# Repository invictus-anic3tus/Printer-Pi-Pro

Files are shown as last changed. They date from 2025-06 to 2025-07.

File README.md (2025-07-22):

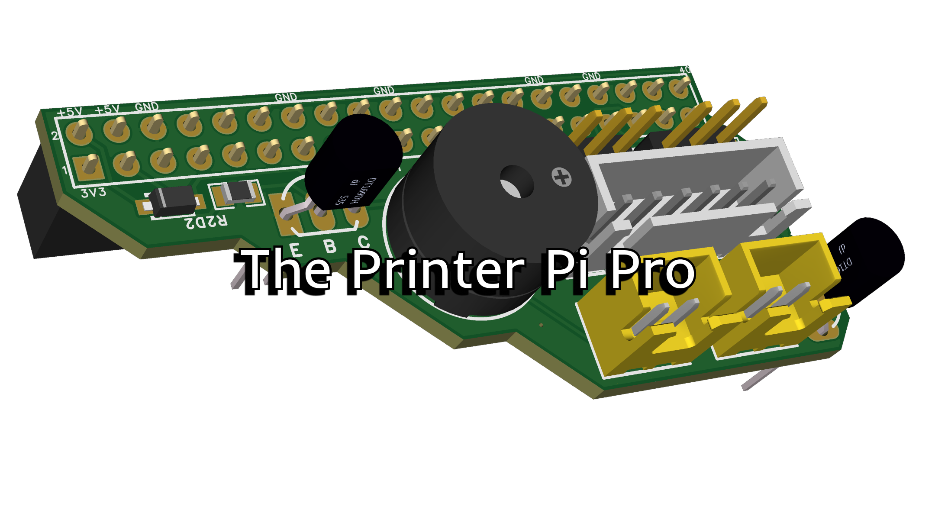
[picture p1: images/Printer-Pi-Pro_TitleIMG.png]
Title Image
# 

<h3 align="center">The all-in-one Raspberry Pi hat for controlling your 3D printer!</h3>

<p align="center">
  
  
</p>

The Printer Pi Pro is a Raspberry Pi HAT for a Klipper or Octoprint 3D printer host. The HAT controls things like servos, an accelerometer, a fan for cooling the pi, and more. It also controls a relay that can turn your printer on or off!

## Contents!! Yay!!
- [Features](#features)
- [Setup](#setup)
  - [Buzzer](#music-with-the-buzzer)
  - [Fan](#controlling-the-fan)
  - [Servos](#controlling-servos)
  - [Input Shaping](#input-shaping-with-the-adxl345)
  - [Relay](#controlling-the-relay)
- [Ordering](#ordering)
  - [BOM](#bom) 
- [Contributing](#contributing)

## What you need:
1. A raspberry pi (duh) with Klipper or Octoprint installed (all features are compatible with both!)
2. The Printer Pi Pro PCB

If you aren't controlling anything with the PCB, that's all you need! However, you likely won't just make the PCB solely to put it on the Pi and not plug anything into it. So here's what you can do with it:

# Features:
1. Onboard passive buzzer: can create little tunes and jingles when your print starts, finishes, cancels, or anything else you want!
2. 5V Fan port: for active cooling your Raspberry Pi. You can code this to turn on when the Pi starts getting hot.
3. Two servo ports: perfect for pitch and yaw of a webcam! or anything else really
4. ADXL345 port: for an accelerometer and input shaping!
5. Relay port: to control an AC or DC relay. This can be for lights, or to turn on/off the printer. More on this later.

# Setup

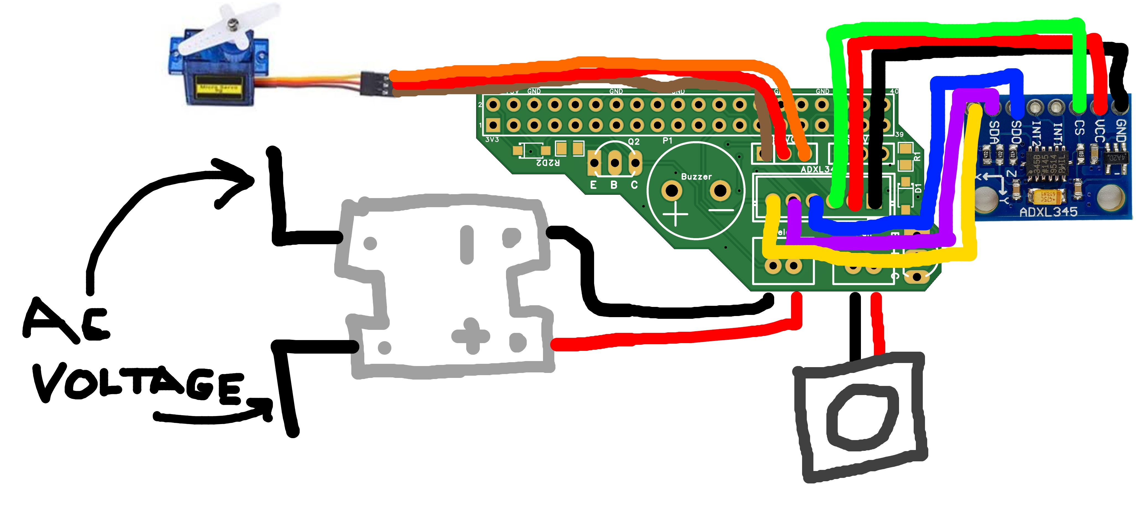
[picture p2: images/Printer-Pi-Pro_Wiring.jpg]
Wiring


|Part |Pins |
|---|---|
|Buzzer |PWM GPIO3 |
|Fan |PWM GPIO18 |
|Servo 1|PWM GPIO13 |
|Servo 2|PWM GPIO19 |
|ADXL |SPI Interface  |
|Relay  |GPIO2 (Not PWM)|

## Music with the buzzer

How to play music with the passive buzzer on the Pi with a script: [https://www.circuitbasics.com/how-to-use-buzzers-with-raspberry-pi/](https://www.circuitbasics.com/how-to-use-buzzers-with-raspberry-pi/) However, 3D printer firmware doesn't natively support running Raspberry Pi scripts using Gcode. In Klipper firmware, you can do it with Gcode with the [Gcode Shell Commands extension](https://github.com/dw-0/kiauh/blob/master/docs/gcode_shell_command.md). In Octoprint + Marlin, use [this](https://plugins.octoprint.org/plugins/gcodesystemcommands/). The buzzer here is connected to GPIO 3.

## Controlling the fan

The fan port is connected to a transistor circuit which turns the two-pin 5V fan on or off using GPIO 18. Additionally, using GPIO 18's PWM signal, you can put the fan at a percentage of speed, for example 25% speed when the Pi is at 40°C, 50% at 45°C, and so on. To change the PWM frequency via a Raspberry Pi script, simply use something like:

```
import RPi.GPIO as GPIO
import time

FAN_PIN = 18 # we're using GPIO 18
FREQ = 25000  # 25khz PWM frequency makes the fan smooth

GPIO.setmode(GPIO.BCM)
GPIO.setup(FAN_PIN, GPIO.OUT)

pwm = GPIO.PWM(FAN_PIN, FREQ)
pwm.start(0)  # Start with fan off

pwm.ChangeDutyCycle(25) # 25% speed
time.sleep(3)
pwm.ChangeDutyCycle(50) # 50% speed
time.sleep(3)
pwm.ChangeDutyCycle(75) # 75% speed
time.sleep(3)
pwm.ChangeDutyCycle(100) # 100% speed

pwm.ChangeDutyCycle(0)
pwm.stop()
GPIO.cleanup()
```

There are more example scripts in the example_scripts folder!

## Controlling servos

Servos are quite easy to control! Here's a good instructables guide: [https://www.instructables.com/Controlling-Servo-Motor-Sg90-With-Raspberry-Pi-4/](https://www.instructables.com/Controlling-Servo-Motor-Sg90-With-Raspberry-Pi-4/) You can control your shell scripts the same way you do with the buzzer scripts. You can use the servos to extend a Klicky docking arm, move a webcam, or clear the build plate. Servo 1 is connected to GPIO 13, and Servo 2 is connected to GPIO 19, which are both PWM pins.

## Input shaping with the ADXL345

If you don't already know, input shaping is the method of using an accelerometer to measure vibrations when moving the 3D printer parts at high speeds. Normally, these vibrations can cause ringing issues in the print, but with input shaping, the printer is able to compensate and use the vibrations and minimize ringing substantially. The ADXL345 connector on the board uses the same pinout as both of the below links do.

Input shaping for Octoprint + Marlin: [https://community.octoprint.org/t/octoprint-pinput-shaping-a-plugin-to-test-input-shaping-with-marlin/63089](https://community.octoprint.org/t/octoprint-pinput-shaping-a-plugin-to-test-input-shaping-with-marlin/63089)

Input shaping for Klipper: [https://www.klipper3d.org/Resonance_Compensation.html](https://www.klipper3d.org/Resonance_Compensation.html)

## Controlling the relay

The relay port simply outputs 5V from the main power source, meaning it can draw up to 800mA through the 2N2222A transistor. You could actually use it for any low-power 5V device you wish, but I think most people will use it for a relay. You can use it to switch 24V from the PSU using a DC-DC relay, or, like I am, you can use it to switch an AC relay. Simply connect 5V to the input voltage on your relay, and GPIO2 to the ground. Note that this does _not_ go straight to GPIO2. I labelled it that simply as a reference as to which GPIO you should set in your script. In reality, it goes through a transistor circuit just like the fan's.

This port, however, does not have a PWM output like the fan does. You could attach a fan to it, but it could only run at 0% or 100%. So the on/handle-interupts script (we'll call it relay-service.py) could look something like:

```
import RPi.GPIO as GPIO
import time
import signal
import sys

RELAY_PIN = 2 # we're using GPIO 2

def cleanup(sig, frame)
    GPIO.cleanup() # this sets everything low, turning off the relay
    sys.exit(0) # exits with success

GPIO.setmode(GPIO.BCM)
GPIO.setup(RELAY_PIN, GPIO.OUT)
GPIO.output(RELAY_PIN, GPIO.HIGH) # switch the relay on

signal.signal(signal.SIGINT, cleanup) # this handles Ctrl+C's and other interruptions
signal.signal(signal.SIGTERM, cleanup) # this handles systemd's termination signals

while True: # this doesn't let the script turn off until it's interrupted or ended
    time.sleep(1) # wait for one second between loops, so as not to overload the system lol
```

You could put this simply in a folder like /home/pi/relay/ for easy access.

Next, we have to make an off script, like the following:

```
import RPi.GPIO as GPIO

RELAY_PIN = 2 # we're using gpio 2
GPIO.setmode(GPIO.BCM) # use gpio numbers instead of pin numbers
GPIO.setup(RELAY_PIN, GPIO.OUT) # set it to be an output
GPIO.output(RELAY_PIN, GPIO.LOW) # turn it off
GPIO.cleanup() # clean up and exit gracefully
```

Now, make the systemd service. You can make the relay start up when the Pi powers on, so that you only have to turn on the Pi and the printer turns on afterwards. First, open `/etc/systemd/system/` and create a new file such as `relay-control.service`. Paste the following:

```
[Unit]
Description=GPIO2 Relay Controller
After=network.target

[Service]
Type=simple
Restart=always
RestartSec=1
User=pi
ExecStart=/usr/bin/python3 /home/pi/relay/relay-service.py
ExecStop=/usr/bin/python3 /home/pi/relay/relay-off.py

[Install]
WantedBy=multi-user.target
```

What the above does is setup a service, just like Klipper is a service and Crowsnest is a service. It sets it to be simple, meaning it doesn't fork. It always restarts if it stops or crashes, and waits a second between attempts. It runs the script as the user pi (replace this with your admin user) and when starting, runs relay-service.py, and when it's stopped it runs relay-off.py. This means that when you first start the script, i.e., on boot, it runs relay-service.py, turning on the relay, and when you run the command to stop it, `sudo systemctl stop relay-control`, or if you power off the pi, it powers off the relay using relay-off.py or through relay-service.py's cleanup() function.

Now, if you want to, you can first reload systemd with `sudo systemctl daemon-reload`, and then enable the service to start up every time the Pi boots! You can do this with `sudo systemctl enable relay-control`. This won't start it immediately after running; to do that you can run `sudo systemctl start relay-control`.

However, the on script is actually only a failsafe. GPIO2, which controls the relay, is actually pulled-up by default, meaning that by default it turns on at boot, without any script. It's still a good idea to have the script, in case the default had been accidentally overriden. If you'd like to override this and not turn on the relay with the Pi, simply edit `/boot/firmware/config.txt` and add the line `gpio=2=pd` somewhere without a [bracketed] header.

Pretty straightforward! However, where this feature can shine the most, is turning the printer on or off remotely. To do this, simply use this extension for Klipper: [Gcode Shell Commands extension](https://github.com/dw-0/kiauh/blob/master/docs/gcode_shell_command.md), or in Octoprint + Marlin, use [this one](https://plugins.octoprint.org/plugins/gcodesystemcommands/). You can add the commands `sudo systemctl start relay-control` to turn it on and `sudo systemctl stop relay-control` to turn it off as GCode commands in your printer's interface. But the issue here is, you can't run GCode while the printer is off! In this case, you'd have to SSH into the Pi and turn it on by manually running the script, or simply reboot the Pi if you've configured the service to start on boot.

## Note:
if you do decide to use an AC relay with this, always be sure that shorts can never occur! AC voltage is really really powerful, and you could get badly injured if you don't wire it correctly. That's all!

# Ordering
The PCB Gerber files, BOM, and CPL (Pick-in-place) file are all in the PCB_Files folder. What I did was order just the PCB (not assembled) through JLCPCB, then combine it with an LCSC order as described [here](https://lcsc.com/faqs/notice?id=D2E15B9830B18723CDFFC807606915A6). Alternatively, you could order an assembled PCB or buy a PCB with the parts not assembled. Unfortunately, JLC only gives you the parts if you buy the PCB assembled. All the parts can be ordered from LCSC; you can also download the cart from the PCB_Files folder.

You'll also need some JST-XH wire housings to fit into the ports on the PCB. If you're combining an LCSC order and a JLCPCB order as mentioned above, you can simply add these to the cart. For example, [this](https://lcsc.com/product-detail/Housings-Wire-To-Board-Wire-To-Wire_JST-XHP-6_C144405.html) is a 6-pin housing to fit into the ADXL345 port. If you're getting an assembled PCB from JLCPCB, you'll have to buy the housings separately, whether through JLCPCB's part cart or a seller such as AliExpress or Amazon.

Also, keep in mind that there's only one component on the bottom side of the PCB: the Raspberry Pi pinheader. This was another reason I bought from LCSC and combined the shipping with JLCPCB, because if I had gotten an assembled PCB from JLC, I would've had to either get a double-sided PCB or put the header on the front, desolder it, and re-solder it onto the back. The PCB also has 4 SMD components. They aren't anything super hard to solder, just two 0805 size resistors and two SOD123F size diodes.

## BOM
|Part |Link |Per Part|Quantity |Total |
|---|---|---|---|---|
|PCB (No parts) |https://jlcpcb.com |$2.10 |1 |$2.10 |
|1N4148W Diode |https://lcsc.com/product-detail/image/1N4148W_C81598.html |$0.01 |50 |$0.54 |
|6P JST-XH Port |https://lcsc.com/product-detail/Wire-To-Board-Connector_JST-B6B-XH-A-GU_C265366.html |$0.42 |5 |$2.11 |
|2P JST-XH Port |https://lcsc.com/product-detail/image/B2B-XH-A-LF-SN_C158012.html |$0.03 |20 |$0.69 |
|0805 Resistor |https://lcsc.com/product-detail/Chip-Resistor-Surface-Mount_Viking-Tech-ARG05FTC5000_C2828857.html|$0.01 |50 |$0.45 |
|2N2222A Transistor |https://lcsc.com/product-detail/image/2N2222A_C5330385.html |$0.02 |50 |$0.87 |
|Passive Buzzer |https://lcsc.com/product-detail/image/YS-MBZ12085C05R42_C409842.html |$0.14 |5 |$0.68 |
|3P Pinheader |https://lcsc.com/product-detail/image/PZ254V-11-03P_C2937625.html |$0.02 |50 |$0.75 |
|2x20P Socket header|https://lcsc.com/product-detail/image/2-54-2-20_C2977589.html |$0.19 |5 |$0.97 |
|6P JST-XH Housing  |https://lcsc.com/product-detail/image/XHP-6_C144405.html |$0.03 |20 |$0.52 |
|AC Relay |https://www.amazon.com/gp/product/B08GPB7N2T/ |$11.79  |1 |$11.79 |
|5V DC Fan |https://lcsc.com/product-detail/image/MF40100V2-1000C-A99_C456919.html |$2.59 |1 |$2.59 |
|-------------------| |--------| |-----------------------|
| | | |Total |$24.05 |
| | | |Shipping + Tax|~$20 (merging JLC+LCSC)|

# Contributing
This is a pretty simple project, but if you have any ideas on things to add, anything in here that could be updated, etc, feel free to make an issue on this repo or email me! (email is in [my profile](https://github.com/invictus-anic3tus))

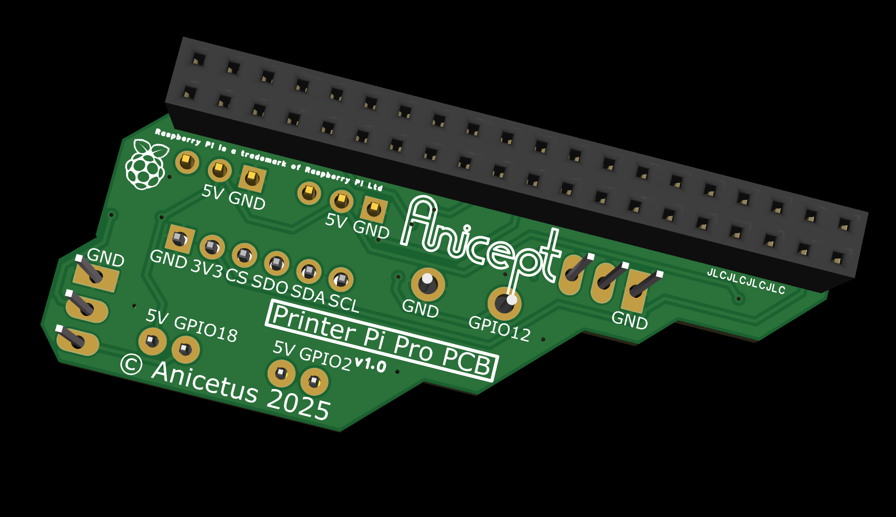
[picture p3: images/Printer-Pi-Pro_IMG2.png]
Ending Image


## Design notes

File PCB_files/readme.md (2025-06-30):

Here you'll find the PCB and schematic files, as well as the Gerbers and bill of materials.

For some reason the 3D model file keeps exporting blue instead of green, but you get the idea. Also note that the Altium Designer files are more likely than not going to be messed up when importing, so a bit of patchwork may be necessary. Here's a schematic picture in case this happens:

Printer-Pi-Pro_Schematic

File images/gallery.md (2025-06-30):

Front of the PCB model

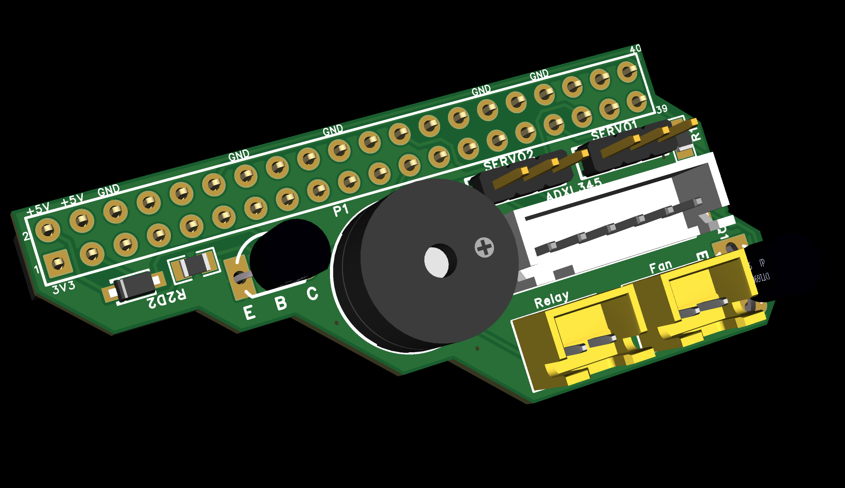
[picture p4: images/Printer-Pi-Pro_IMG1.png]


Back of the PCB model



R2D2! (Resistor two and diode two were right next to each other... I couldn't _resist_ it)

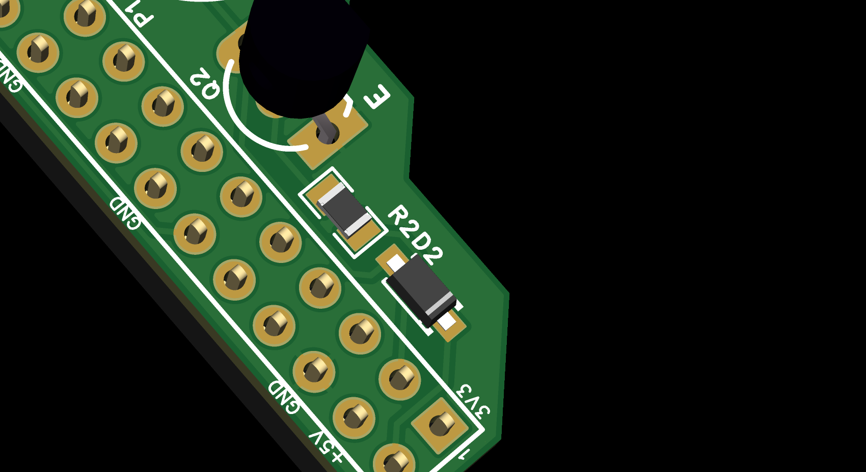
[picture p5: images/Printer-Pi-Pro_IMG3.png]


JST-XH ports for convenience

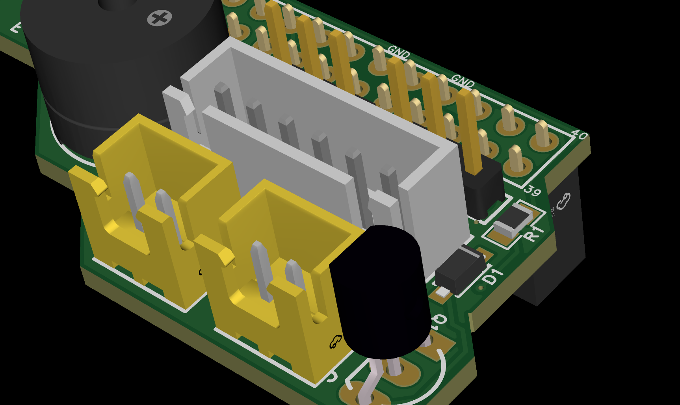
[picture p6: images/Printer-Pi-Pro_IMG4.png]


Circuit board model front only

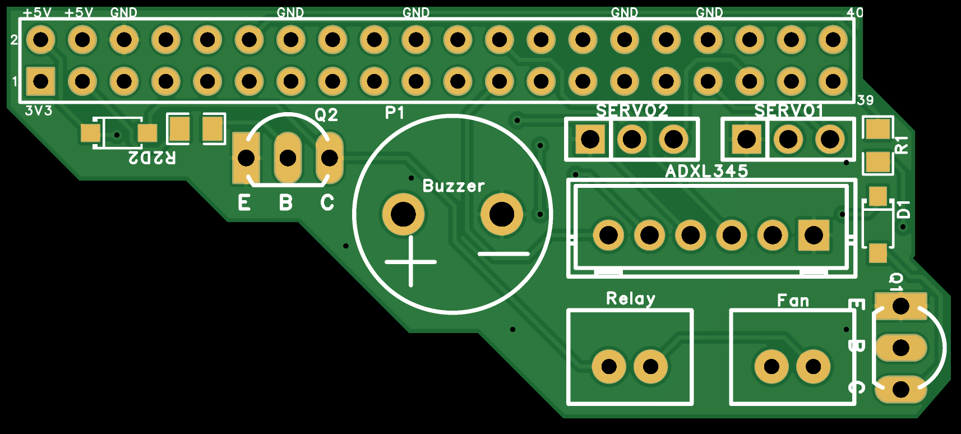
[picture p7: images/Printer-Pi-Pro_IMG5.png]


Circuit board model back only

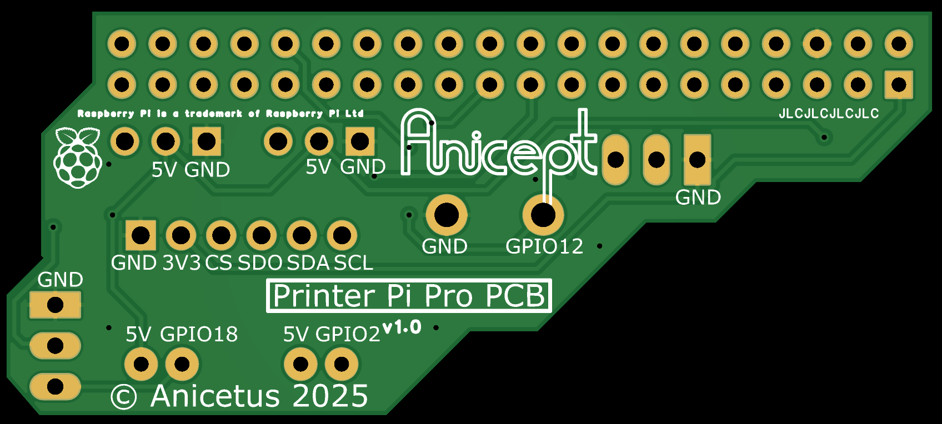
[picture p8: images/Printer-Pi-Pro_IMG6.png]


PCB Front

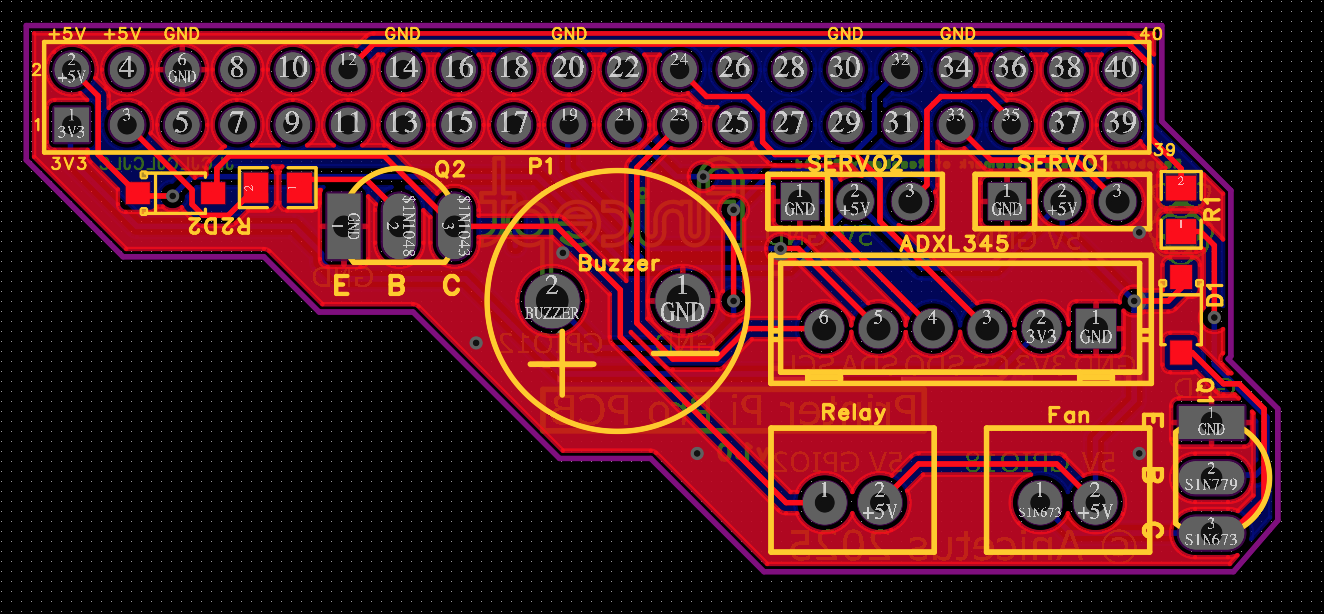
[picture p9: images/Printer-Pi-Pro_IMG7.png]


PCB Back

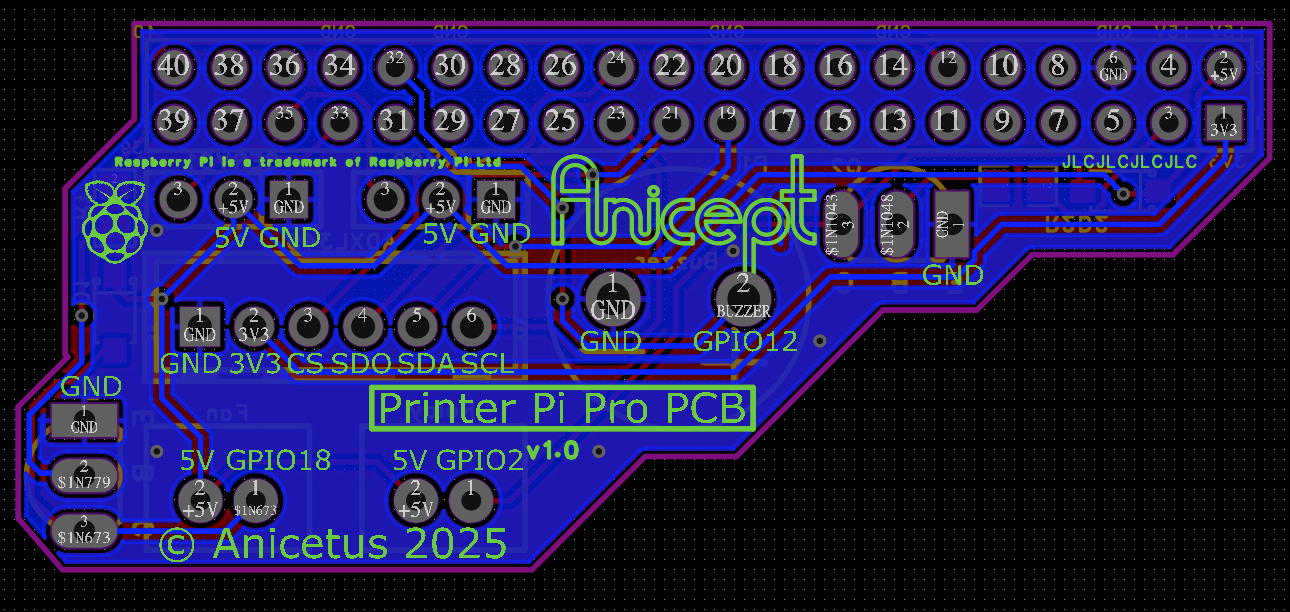
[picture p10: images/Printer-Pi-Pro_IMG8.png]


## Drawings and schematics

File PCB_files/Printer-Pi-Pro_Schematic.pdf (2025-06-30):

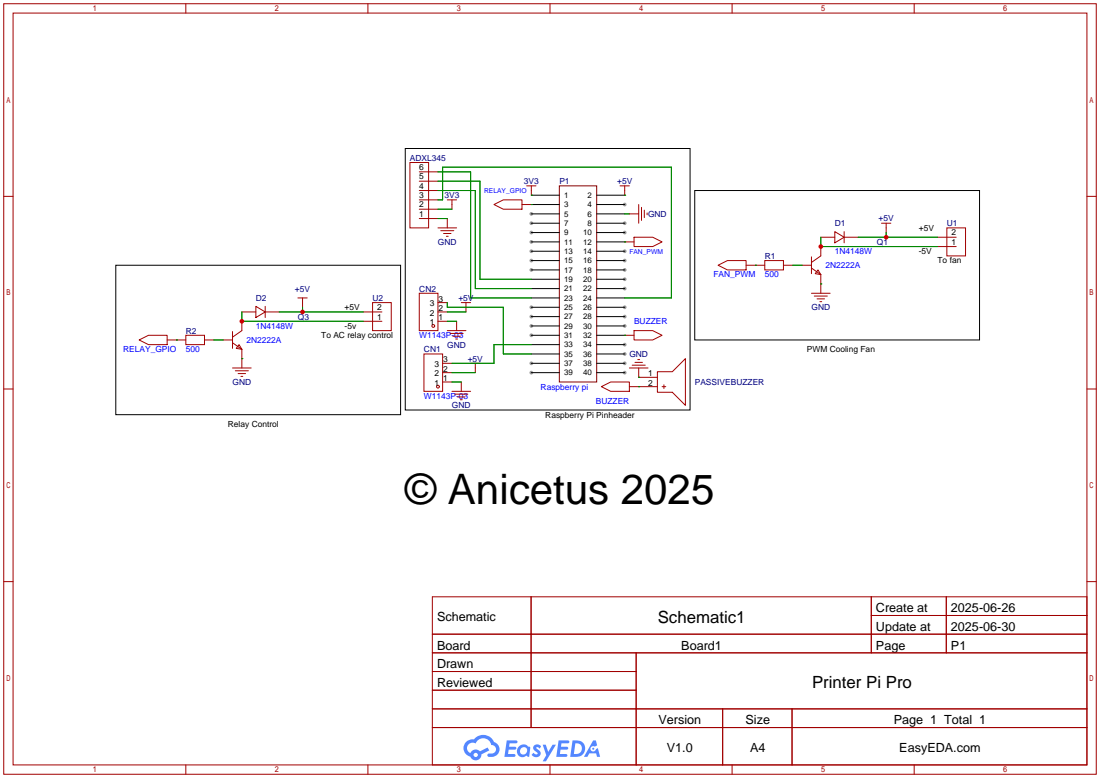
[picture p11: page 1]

Schematic | Schematic1 | Create at | 2025-06-26

Update at | 2025-06-30

Board | Board1 | Page | P1
Drawn | | Printer Pi Pro
Reviewed

Version | Size | Page 1 Total 1
V1.0 | A4 | EasyEDA.com

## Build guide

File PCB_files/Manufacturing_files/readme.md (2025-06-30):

Gerber files, BOM file, Pick-in-place (CPL) file, and the LCSC cart BOM (see [ordering](https://github.com/invictus-anic3tus/Printer-Pi-Pro/blob/main/README.md#ordering))

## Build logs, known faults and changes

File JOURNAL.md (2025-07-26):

---
title: "The Printer Pi Pro"
author: "Anicetus"
description: "The all-in-one Raspberry Pi 3D printer add-on!"
created_at: "2025-06-26"
---

## total time: 20 hrs

# firstly

i want to thank everybody at hack club who's making this possible. if you don't know, hack club is a 100% 501(c)(3) nonprofit run by zach latta + friends made for coders and electronics peoples 18 and under. this project is made possible through their highway to undercity program, where teens are empowered to build their dreams with up to $350 in funding!

so a big thank you out to acon, alex ren, cyao, ducc, bunnyguy, phthallo, paolo, kareem, rhys, kl, ian, tongyu, manitej, cinders, and m0hid!!

## i'm anicetus
if you're reading this on hack club, you may very well already know me. but if you dont, here's a bit of info:
1. I live in the usa
2. i'm ok at coding
3. but i think im pretty good at electronics and stuff!
4. i've designed (most of) a custom keyboard
5. and a custom 3d printer

so yeah i've got a bit to put on my resume! but anyways let's get down to business.

# log

### Day one - june 26
So i want to make this for the raspberry pi running my homemade 3D printer. right now if my printer is off, i have to be physically there to turn it on, and that's no fun! Additionally, if i'm away from home and will be for a while, I'd want to be able to turn the PSU and mainboard and stuff off while it's idle. So I thought to meself, "well now, how would i be able to turn on or off my 3d printer with just the interface on me raspberry pi?"

I did a tad bit of research, and found out the answer was simple: a relay! I simply connect the relay to the AC power going to my PSU, and the raspberry pi can turn it on or off. however, those relays take a good amount of amperage to work, and the raspberry pi's gpio pins don't exactly give that much. so, we need a transistor circuit to be able to switch 5V from the main power supply to power the relay! nice!

then i though to meself: "why stop at just controlling a relay? as long as i'm making this thing, i could control other things as well!" turns out the transistor circuit from before is perfect for running a two-pin 5V fan. easy enough. i also wanna power servos, an adxl345 accelerometer (input shaping!) and maybe some other peripherals.

I started making the PCB, and got the schematic done and the footprints added. I had to do a bunch of research about solid state relay amperage, raspberry pi pwm outputs, servos, and more to get started. i also added a buzzer, hopefully to make music and little beeps!

3 hrs

### day two - june 27
Today i pretty much finished the PCB! I placed all the components (all on one side for single-side assembly!), routed the wires, and learned how to do copper pours. I added some ground pours both cuz they're cool and because it makes it easy to route ground. It's looking quite good!







R2D2!  


I think i want to manufacture it green to match the Rpi. Right now, the PCB uses the two transistor circuits to control the fan and the relay (and i realized you can actually control any 5V device with it that uses less than 800mA), two PWM gpios to control servos, a gpio to control the buzzer, and SPI communication to the ADXL345 port. I made a ton of progress today, which I'm proud of.

2.5 hrs

### day three - june 28
today i plan to finish this thing! It's a pretty simple and small project, but i'm happy im able to make pcbs this quickly now. I did a bit of factchecking and realized I need the buzzer on a PWM pin, not just any old GPIO. I unrouted it, fixed the schematic, deleted my copper pours, _re-_routed it, and finally redid my copper pours. perfect! I've been making this thing in easyeda instead of kicad, because I used it once on a computer without Kicad and thought it'd be nice to learn another eda program. turns out, it's actually super... well... easy!

However, I realized that I can't export kicad files (which everybody uses) from easyeda... welp. I can, however, export Altium files! I think KiCad can import those. According to EasyEDA, sometimes Altium exports come out wrong. So if you need to import it into Altium or KiCad, know that you may need to do some patchwork. Here's some pics for reference: (ignore the giant copyright :yum:)

Printer-Pi-Pro_Schematic_Reference

2 hrs

### day four - june 29
today i exported everything, uploaded it, made sure jlcpcb checkout works, and figured out you can combine jlc and lcsc orders! ima do that + get my parts from lcsc since its cheaper than pcba. no design today, just exporting all the files and such.

1 hr

### day five - june 30
today i double checked my connections, and realized the relay and fan ports were backwards. i fixed the schematic, updated the PCB... and it didn't work. eventually i figured out that i had to manually change the tracks on the footprint on the PCB, which is kinda strange. i also labelled the PCB, to make it more user-friendly. I updated the scripts a bit, and added some example ones. time to submit!!!

2 hrs

### day six - july 14
today I received the stuffs! I soldered everything up and it looks great :D

no pics yet, im working on my next project now :)

1.5 hrs

### day seven - july 23
today i finally hooked the thing up and started firmware, but turns out I used GPIO2 for relay control, which is by default pulled high, keeping the relay on no matter what I do! I had to do circuit surgery and manually connect it to GPIO4 instead, but it works perfectly now! I'm proud of my beautiful surgical operation lol

3 hrs

### day eight - july 25
today I got the ADXL working! I ran the input shaper and I believe it helped the print quality... if only slightly.

2.5 hrs

### day nine - july 26
today I got the buzzer working, and played some funny tunes! It's honestly quite silly hearing my 3D printer sing songs to me. I used GCode shell commands to have it play the Super Mario flagpole fanfare after finishing prints!

2.5 hrs

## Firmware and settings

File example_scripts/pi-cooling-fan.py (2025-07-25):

import RPi.GPIO as GPIO
import time
from gpiozero import CPUTemperature # make sure to install gpiozero if it isn't already

FAN_PIN = 18 # we're using GPIO 18
FREQ = 25000  # 25khz PWM frequency makes the fan smooth

GPIO.setmode(GPIO.BCM)
GPIO.setup(FAN_PIN, GPIO.OUT)

pwm = GPIO.PWM(FAN_PIN, FREQ)
pwm.start(0)  # Start with fan off

cpu = CPUTemperature()
temp = cpu.temperature # grab cpu temp

def cleanup(sig, frame):
    pwm.ChangeDutyCycle(0)
    pwm.stop()
    GPIO.cleanup()
    sys.exit(0) # exits with success

signal.signal(signal.SIGINT, cleanup) # this handles Ctrl+C's and other interruptions
signal.signal(signal.SIGTERM, cleanup) # this handles systemd's termination signals

try:
  while True:
    temp = cpu.temperature # update temp reading
    if temp < 30: # 30°C or less
      pwm.ChangeDutyCycle(0)
    elif temp < 40: # 30°-40°
      pwm.ChangeDutyCycle(25)
    elif temp < 50: # 40°-50°
      pwm.ChangeDutyCycle(50)
    else: # 50°+
      pwm.ChangeDutyCycle(100)
  
    time.sleep(2) # wait two seconds to not consume CPU (and make temp go up!)
except KeyboardInterrupt:
  print("Keyboard interrupt received")
finally:
    pwm.ChangeDutyCycle(0)
    pwm.stop()
    GPIO.cleanup()
  

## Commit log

2025-06-28 Add .pcbdoc and .schdoc files (Altium)
    [Printer-Pi-Pro_PCB.pcbdoc, Printer-Pi-Pro_Schematic.schdoc]
2025-06-29 Update schematic doc file
    [Printer-Pi-Pro_Schematic.schdoc]
2025-06-29 Update PCB doc file
    [Printer-Pi-Pro_PCB.pcbdoc]
2025-06-29 Add gerbers
2025-06-29 Add manufacturing files
    [Printer-Pi-Pro_BOM.csv, Printer-Pi-Pro_LCSC-Cart.csv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]
2025-06-30 Update altium designer files
    [Printer-Pi-Pro_Altium_PCB.pcbdoc, Printer-Pi-Pro_Altium_Schematic.schdoc]
2025-06-30 Haha delete more old altium files
    [Printer-Pi-Pro_PCB.pcbdoc]
2025-06-30 Update PCB model file
2025-06-30 add schematic pdf
2025-06-30 Add full BOM
    [Printer-Pi-Pro_Full_BOM.csv]
2025-06-30 Update README.md - add bom
2025-06-30 Add wiring image
2025-06-30 Update README.md - polishing and add wiring guide
2025-06-30 Update README.md - update code and relay docs
